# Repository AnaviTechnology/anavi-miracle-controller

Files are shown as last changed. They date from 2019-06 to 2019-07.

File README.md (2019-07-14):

# ANAVI Miracle Controller

ANAVI Miracle Controller is an open source hardware development board for controlling 2 12V or 5V addressable LED strips. It features:

* ESP8266 WiFi microcontroller
* Terminals for 2 12V or 5V addressable LED strips (WS2811, WS2812, TM1804, etc.)
* Jumper to select 12V or 5V power input
* Dedicated slot for I2C OLED display
* Slots for up to 3 plug and play I2C sensors for temperature, barometric pressure, humidity and light
* UART (Universal asynchronous receiver/transmitter) pins for debugging

Open source software for ANAVI Miracle Controller written as an [Arduino sketch is also available at GitHub](https://github.com/AnaviTechnology/anavi-miracle-controller-sw).

# License

The project is released under the [Creative Commons Attribution-ShareAlike 4.0 International (CC BY-SA 4.0)](https://creativecommons.org/licenses/by-sa/4.0/).

Note: This is a human-readable summary of (and not a substitute for) the [license](https://creativecommons.org/licenses/by-sa/4.0/legalcode).

You are free to:

Share — copy and redistribute the material in any medium or format Adapt — remix, transform, and build upon the material for any purpose, even commercially. The licensor cannot revoke these freedoms as long as you follow the license terms. Under the following terms:

Attribution — You must give appropriate credit, provide a link to the license, and indicate if changes were made. You may do so in any reasonable manner, but not in any way that suggests the licensor endorses you or your use. ShareAlike — If you remix, transform, or build upon the material, you must distribute your contributions under the same license as the original. No additional restrictions — You may not apply legal terms or technological measures that legally restrict others from doing anything the license permits. Notices:

You do not have to comply with the license for elements of the material in the public domain or where your use is permitted by an applicable exception or limitation. No warranties are given. The license may not give you all of the permissions necessary for your intended use. For example, other rights such as publicity, privacy, or moral rights may limit how you use the material.

You will have to provide a link to the original creator of the project http://www.anavi.technology on any documentation or website.

Credit can be attributed through a link to the creator website: http://www.anavi.technology

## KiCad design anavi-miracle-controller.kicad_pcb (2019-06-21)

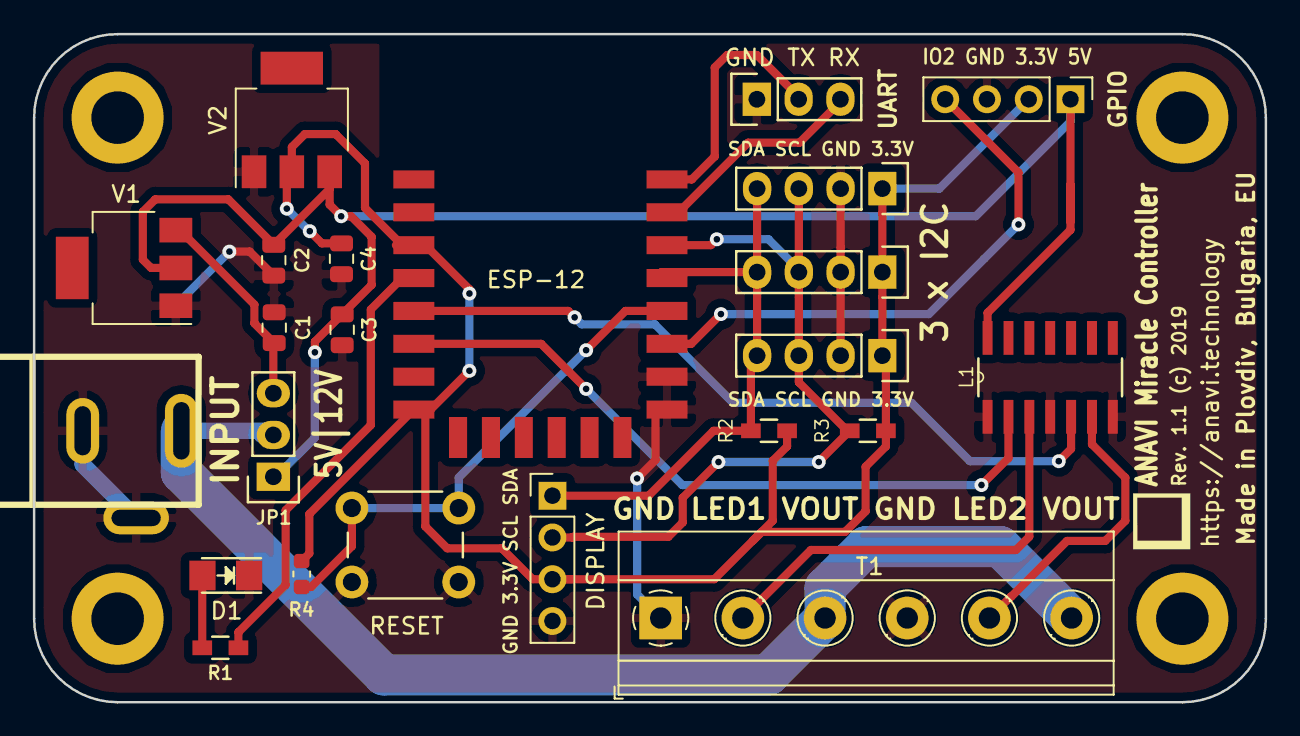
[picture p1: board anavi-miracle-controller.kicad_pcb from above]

Board: 2 copper layers, 74.9 x 40.6 mm, 23 parts (0 on the bottom side), 17 nets.

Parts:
C1, C2, C3, C4: 10uF; C_0805_2012Metric
D1: LED; LED_1206
DISPLAY: Conn_01x04; PinHeader_1x04_P2.54mm_Vertical
ESP-12: ESP-12E; ESP-12E_SMD
GPIO: Conn_01x04; PinHeader_1x04_P2.54mm_Vertical
J1: INPUT; dc_socket
JP1: SolderJumper_3_Open; Pin_Header_Straight_1x03
L1: SN74AHCT125D; SOIC127P600X175-14N
P1: CONN_01X03; Pin_Header_Straight_1x03
R1: 68R; R_0603_HandSoldering
R2, R3: 4,7K; R_0603_HandSoldering
R4: 2K; R_0603_1608Metric
RESET: SW_DIP_x01; SW_PUSH_6mm_h4.3mm
T1: Screw_Terminal_01x06; TerminalBlock_Phoenix_MKDS-1,5-6_1x06_P5.00mm_Horizontal
U1, U2, U3: I2C_SENS_1; Pin_Header_Straight_1x04
V1: NCP1117ST50T3G; SOT-223
V2: NCP1117ST33T3G; SOT-223

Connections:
+3V3: C4.1, DISPLAY.3, ESP-12.3, ESP-12.8, GPIO.2, R2.1, R3.1, R4.2, U1.1, U2.1, U3.1, V2.2
+5V: C2.1, C3.1, GPIO.1, JP1.1, L1.14, V1.2, V2.3
+12V: C1.1, JP1.3, V1.3
/LED1: L1.3, T1.2
/LED2: L1.6, T1.5
GND: C1.2, C2.2, C3.2, C4.2, D1.1, DISPLAY.4, ESP-12.9, ESP-12.10, GPIO.3, J1.1, J1.2, L1.1, L1.4, L1.7, P1.1, RESET.1, T1.1, T1.4, U1.2, U2.2, U3.2, V1.1, V2.1
unnamed: D1.2, R1.2
unnamed: ESP-12.4, R1.1
unnamed: ESP-12.5, L1.5
unnamed: ESP-12.6, L1.2
unnamed: ESP-12.11, GPIO.4
unnamed: ESP-12.12, R4.1, RESET.2
unnamed: DISPLAY.1, ESP-12.13, R2.2, U1.4, U2.4, U3.4
unnamed: DISPLAY.2, ESP-12.14, R3.2, U1.3, U2.3, U3.3
unnamed: ESP-12.15, P1.3
unnamed: ESP-12.16, P1.2
unnamed: J1.3, JP1.2, T1.3, T1.6

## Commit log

2019-06-01 Intial release
    [anavi-light-controller-2018-09-18-17-42-49.sch, anavi-light-controller-2018-09-19-00-00-35.sch, anavi-light-controller-2018-09-19-09-35-14.sch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]
2019-06-01 Update schematics and PCB design
    Major update to add SN74AHCT125D and to make the PCB design.
    [anavi-miracle-controller.kicad_pcb, anavi-miracle-controller.sch]
2019-06-01 anavi-miracle-controller.kicad_pcb: Fix outline
    Fix the outline to export properly gerber and drill files.
    [anavi-miracle-controller.kicad_pcb]
2019-06-01 anavi-miracle-controller.kicad_pcb: Labels
    Improve text labels and their positions.
    [anavi-miracle-controller.kicad_pcb]
2019-06-03 anavi-miracle-controller.kicad_pcb: Improvements
    Minor improvements of rev 1.0.
    [anavi-miracle-controller.kicad_pcb]
2019-06-09 Revision 1.1: Fix DC Jack
    Update the schedatics, fix the DC jack on the PCB.
    [anavi-miracle-controller.kicad_pcb, anavi-miracle-controller.sch]
2019-06-21 anavi-miracle-controller.kicad_pcb: Assembly
    Update assembly guidelines on the board.
    [anavi-miracle-controller.kicad_pcb]

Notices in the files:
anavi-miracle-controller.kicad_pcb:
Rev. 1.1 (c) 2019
